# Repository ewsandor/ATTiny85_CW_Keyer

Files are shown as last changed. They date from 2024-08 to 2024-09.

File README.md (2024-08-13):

# ATTiny85_CW_Keyer
A full-featured CW keyer for amateur radio use. The keyer is built around a cheap and tiny ATTINY85 microcontroller. The circuit boasts 4-100 character memories, beacon mode, multiple timing options, and a CW trainer for improving your Morse code speed.

## Printed Circuit Board
This fork provides design files to build a PCB for this project.

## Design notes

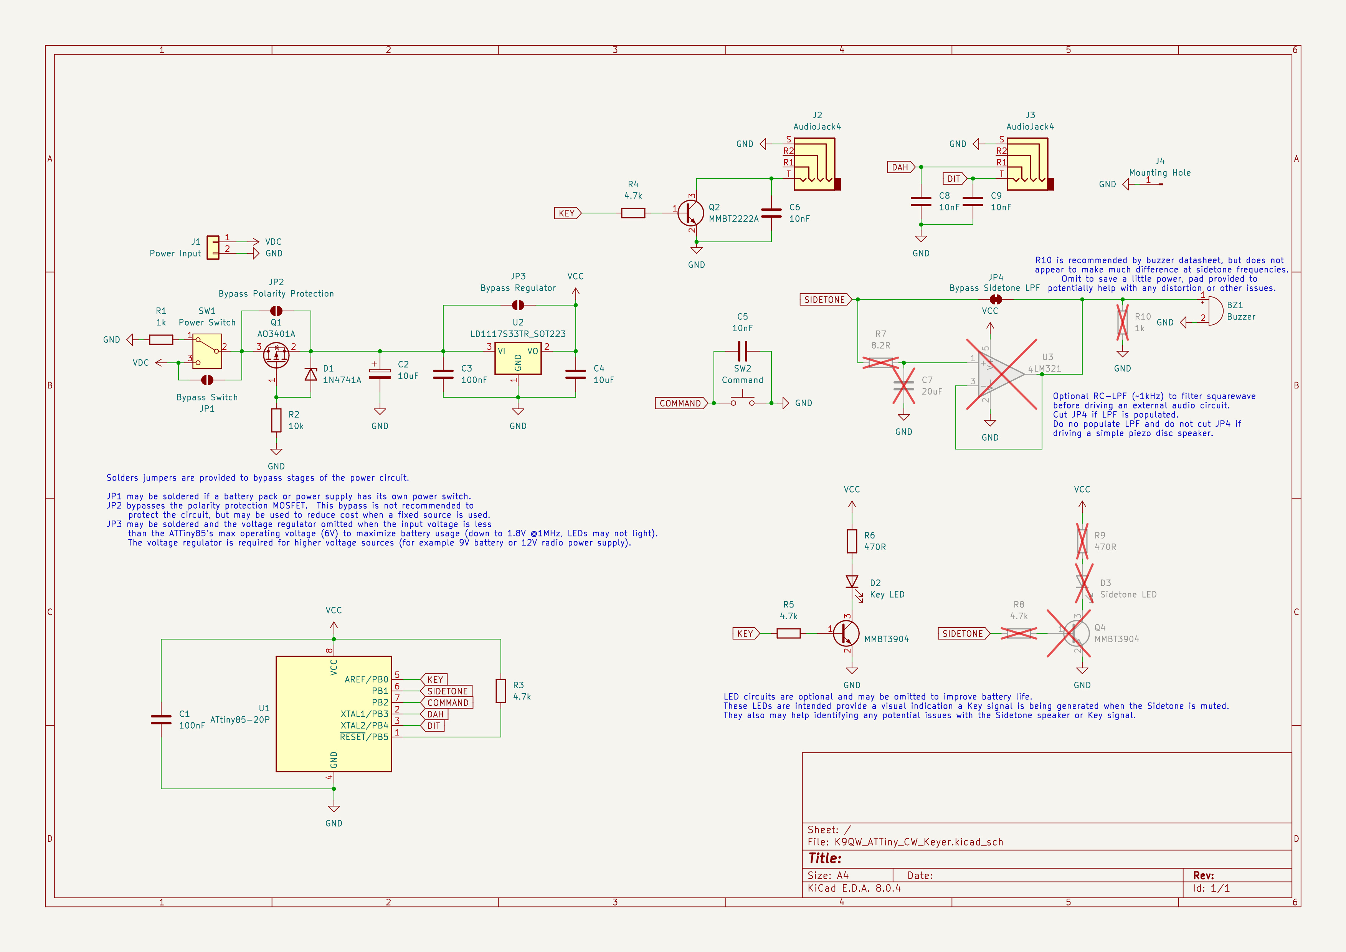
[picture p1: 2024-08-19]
schematic.jpg

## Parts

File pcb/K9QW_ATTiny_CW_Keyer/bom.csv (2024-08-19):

Reference | Value | Footprint | Qty | DNP
BZ1 | Buzzer | Buzzer_Beeper:Buzzer_TDK_PS1240P02BT_D12.2mm_H6.5mm | 1
C1,C3 | 100nF | Capacitor_SMD:C_0603_1608Metric_Pad1.08x0.95mm_HandSolder | 2
C2 | 10uF | Capacitor_THT:CP_Radial_D5.0mm_P2.00mm | 1
C4 | 10uF | Capacitor_SMD:C_0603_1608Metric_Pad1.08x0.95mm_HandSolder | 1
C5,C6,C8,C9 | 10nF | Capacitor_SMD:C_0603_1608Metric_Pad1.08x0.95mm_HandSolder | 4
C7 | 20uF | Capacitor_SMD:C_0603_1608Metric_Pad1.08x0.95mm_HandSolder | 1 | DNP
D1 | 1N4741A | Diode_THT:D_DO-41_SOD81_P3.81mm_Vertical_KathodeUp | 1
D2 | Key LED | LED_SMD:LED_0603_1608Metric_Pad1.05x0.95mm_HandSolder | 1
D3 | Sidetone LED | LED_SMD:LED_0603_1608Metric_Pad1.05x0.95mm_HandSolder | 1 | DNP
J1 | Power Input | Connector_JST:JST_XH_B2B-XH-A_1x02_P2.50mm_Vertical | 1
J2,J3 | AudioJack4 | Connector_Audio:Jack_3.5mm_PJ320D_Horizontal | 2
J4 | Mounting Hole | MountingHole:MountingHole_3.2mm_M3_Pad_TopBottom | 1
Q1 | AO3401A | Package_TO_SOT_SMD:SOT-23 | 1
Q2 | MMBT2222A | Package_TO_SOT_SMD:SOT-23 | 1
Q3 | MMBT3904 | Package_TO_SOT_SMD:SOT-23 | 1
Q4 | MMBT3904 | Package_TO_SOT_SMD:SOT-23 | 1 | DNP
R1 | 1k | Resistor_SMD:R_0603_1608Metric_Pad0.98x0.95mm_HandSolder | 1
R2 | 10k | Resistor_SMD:R_0603_1608Metric_Pad0.98x0.95mm_HandSolder | 1
R3,R4,R5 | 4.7k | Resistor_SMD:R_0603_1608Metric_Pad0.98x0.95mm_HandSolder | 3
R6 | 470R | Resistor_SMD:R_0603_1608Metric_Pad0.98x0.95mm_HandSolder | 1
R7 | 8.2R | Resistor_SMD:R_0603_1608Metric_Pad0.98x0.95mm_HandSolder | 1 | DNP
R8 | 4.7k | Resistor_SMD:R_0603_1608Metric_Pad0.98x0.95mm_HandSolder | 1 | DNP
R9 | 470R | Resistor_SMD:R_0603_1608Metric_Pad0.98x0.95mm_HandSolder | 1 | DNP
R10 | 1k | Resistor_SMD:R_0603_1608Metric_Pad0.98x0.95mm_HandSolder | 1 | DNP
SW1 | Power Switch | Connector_JST:JST_XH_B3B-XH-A_1x03_P2.50mm_Vertical | 1
SW2 | Command | Button_Switch_THT:SW_PUSH_6mm | 1
U1 | ATtiny85-20P | Package_DIP:DIP-8_W7.62mm | 1
U2 | LD1117S33TR_SOT223 | Package_TO_SOT_SMD:SOT-223-3_TabPin2 | 1
U3 | LM321 | Package_TO_SOT_SMD:SOT-23-5 | 1 | DNP

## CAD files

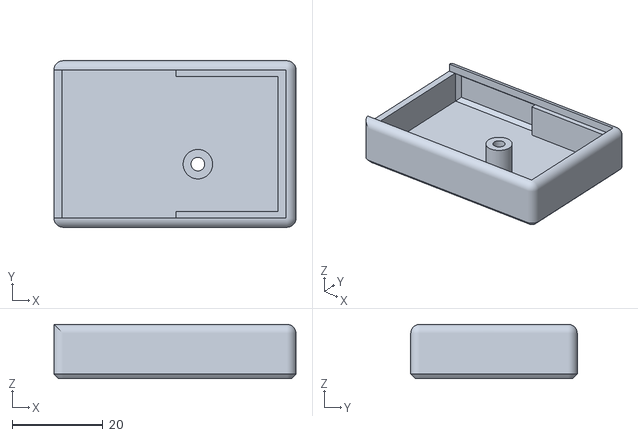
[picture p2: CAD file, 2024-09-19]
pcb/ATTiny85 CW Keyer Enclosure.stl
53.4 x 36.8 x 12.0

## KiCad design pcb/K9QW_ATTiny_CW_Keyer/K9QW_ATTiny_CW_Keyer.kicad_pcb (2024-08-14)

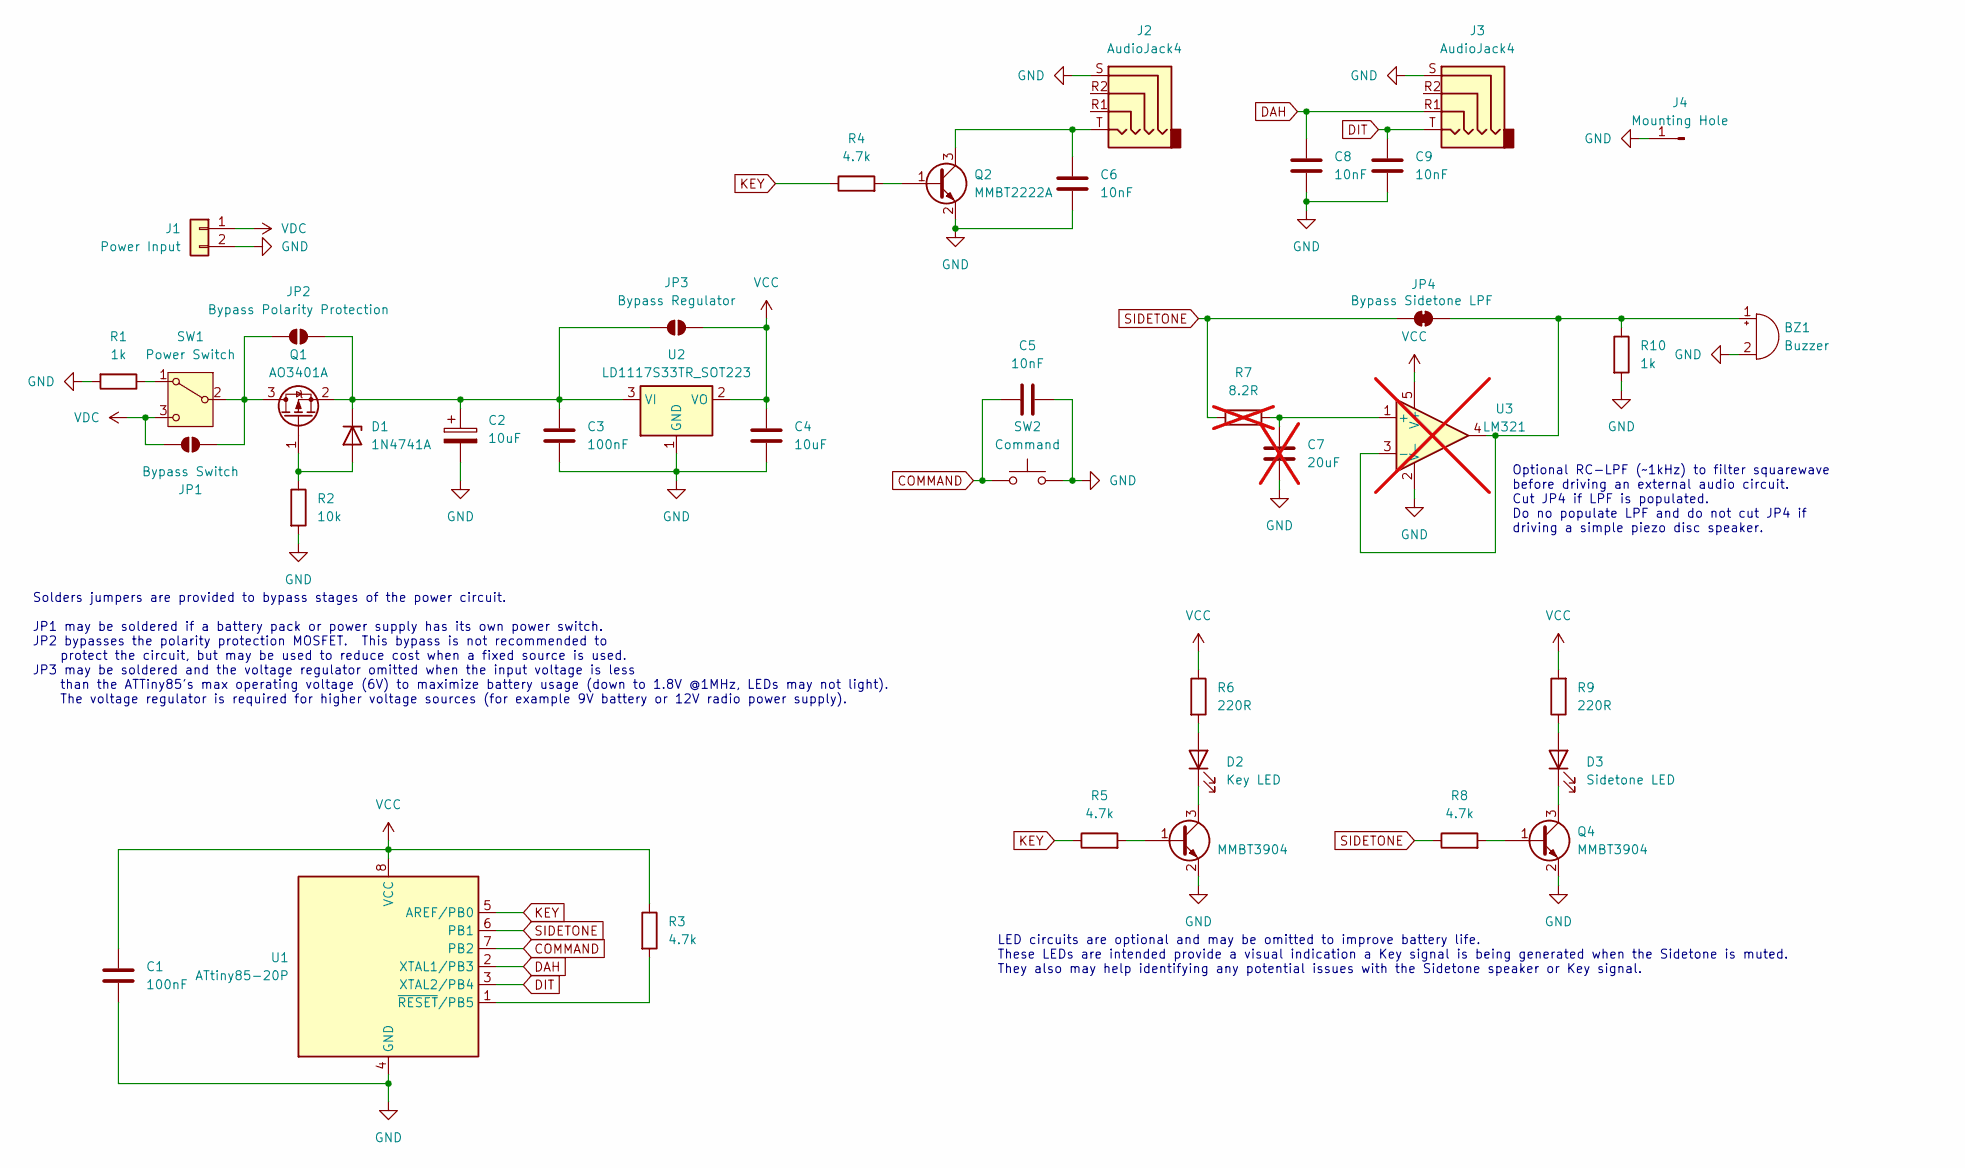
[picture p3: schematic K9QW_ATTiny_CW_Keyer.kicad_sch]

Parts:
BZ1: Buzzer; Buzzer_TDK_PS1240P02BT_D12.2mm_H6.5mm
C1, C3: 100nF; C_0603_1608Metric_Pad1.08x0.95mm_HandSolder
C2: 10uF; CP_Radial_D5.0mm_P2.00mm
C4: 10uF; C_0603_1608Metric_Pad1.08x0.95mm_HandSolder
C5, C6, C8, C9: 10nF; C_0603_1608Metric_Pad1.08x0.95mm_HandSolder
C7: 20uF; C_0603_1608Metric_Pad1.08x0.95mm_HandSolder; not fitted
D1: 1N4741A; D_DO-41_SOD81_P3.81mm_Vertical_KathodeUp
D2: Key LED; LED_0603_1608Metric_Pad1.05x0.95mm_HandSolder
D3: Sidetone LED; LED_0603_1608Metric_Pad1.05x0.95mm_HandSolder
J1: Power Input; JST_XH_B2B-XH-A_1x02_P2.50mm_Vertical
J2, J3: AudioJack4; Jack_3.5mm_PJ320D_Horizontal
J4: Mounting Hole; MountingHole_3.2mm_M3_Pad_TopBottom
JP1: Bypass Switch; SolderJumper-2_P1.3mm_Open_RoundedPad1.0x1.5mm
JP2: Bypass Polarity Protection; SolderJumper-2_P1.3mm_Open_RoundedPad1.0x1.5mm
JP3: Bypass Regulator; SolderJumper-2_P1.3mm_Open_RoundedPad1.0x1.5mm
JP4: Bypass Sidetone LPF; SolderJumper-2_P1.3mm_Bridged_RoundedPad1.0x1.5mm
Q1: AO3401A; SOT-23
Q2: MMBT2222A; SOT-23
Q3, Q4: MMBT3904; SOT-23
R1, R10: 1k; R_0603_1608Metric_Pad0.98x0.95mm_HandSolder
R2: 10k; R_0603_1608Metric_Pad0.98x0.95mm_HandSolder
R3, R4, R5, R8: 4.7k; R_0603_1608Metric_Pad0.98x0.95mm_HandSolder
R6, R9: 220R; R_0603_1608Metric_Pad0.98x0.95mm_HandSolder
R7: 8.2R; R_0603_1608Metric_Pad0.98x0.95mm_HandSolder; not fitted
SW1: Power Switch; JST_XH_B3B-XH-A_1x03_P2.50mm_Vertical
SW2: Command; SW_PUSH_6mm
U1: ATtiny85-20P; DIP-8_W7.62mm
U2: LD1117S33TR_SOT223; SOT-223-3_TabPin2
U3: LM321; SOT-23-5; not fitted

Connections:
COMMAND: C5.1, SW2.1, U1.7 (PB2)
DAH: C8.1, J3.R1, U1.2 (XTAL1/PB3)
DIT: C9.1, J3.T, U1.3 (XTAL2/PB4)
GND: BZ1.2 (-), C1.2, C2.2, C3.2, C4.2, C5.2, C6.2, C7.2, C8.2, C9.2, J1.2, J2.S, J3.S, J4.1, Q2.2 (E), Q3.2 (E), Q4.2 (E), R1.2, R2.2, R10.2, SW2.2, U1.4 (GND), U2.1 (GND), U3.2 (V-)
KEY: R4.1, R5.1, U1.5 (AREF/PB0)
unnamed: BZ1.1 (+), JP4.2 (B), R10.1, U3.3 (-), U3.4
unnamed: D1.2 (A), Q1.1 (G), R2.1
unnamed: C2.1, C3.1, D1.1 (K), JP2.2 (B), JP3.1 (A), Q1.2 (S), U2.3 (VI)
unnamed: D2.2 (A), R6.2
unnamed: D2.1 (K), Q3.3 (C)
unnamed: D3.2 (A), R9.1
unnamed: D3.1 (K), Q4.3 (C)
unnamed: JP1.1 (A), JP2.1 (A), Q1.3 (D), SW1.2 (B)
unnamed: Q2.1 (B), R4.2
unnamed: C6.1, J2.T, Q2.3 (C)
unnamed: Q3.1 (B), R5.2
unnamed: Q4.1 (B), R8.2
unnamed: R1.1, SW1.1 (A)
unnamed: R3.2, U1.1 (~RESET/PB5)
unnamed: C7.1, R7.1, U3.1 (+)
SIDETONE: JP4.1 (A), R7.2, R8.1, U1.6 (PB1)
VCC: C1.1, C4.1, JP3.2 (B), R3.1, R6.1, R9.2, U1.8 (VCC), U2.2 (VO), U3.5 (V+)
VDC: J1.1, JP1.2 (B), SW1.3 (C)

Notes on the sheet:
Optional RC-LPF (~1kHz) to filter squarewave before driving an external audio circuit. Cut JP4 if LPF is populated. Do no populate LPF and do not cut JP4 if driving a simple piezo disc speaker.
LED circuits are optional and may be omitted to improve battery life. These LEDs are intended provide a visual indication a Key signal is being generated when the Sidetone is muted. They also may help identifying any potential issues with the Sidetone speaker or Key signal.
Solders jumpers are provided to bypass stages of the power circuit. JP1 may be soldered if a battery pack or power supply has its own power switch. JP2 bypasses the polarity protection MOSFET. This bypass is not recommended to protect the circuit, but may be used to reduce cost when a fixed source 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

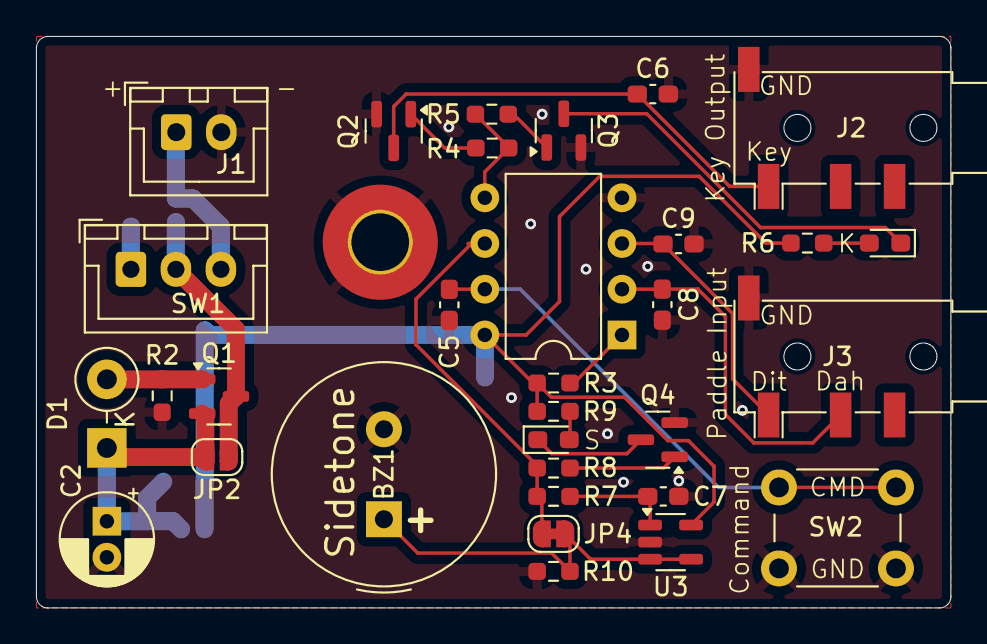
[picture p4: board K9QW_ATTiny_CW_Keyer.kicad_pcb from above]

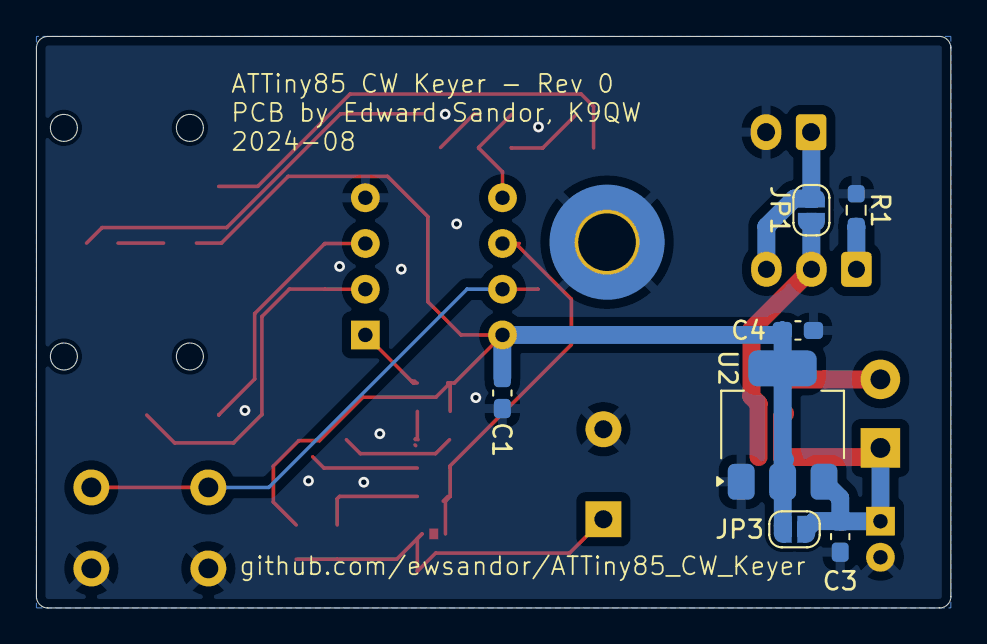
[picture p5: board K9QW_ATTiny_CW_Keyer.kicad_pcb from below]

Board: 2 copper layers, 50.8 x 31.8 mm, 40 parts (7 on the bottom side), 23 nets.

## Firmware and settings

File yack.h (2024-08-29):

/* ********************************************************************
 Program	: yack.h
 Author		: Jan Lategahn DK3LJ modified by Jack Welch AI4SV, Don Froula WD9DMP
 Purpose	: definition of keyer hardware
 Created	: 15.10.2010
 Update		: 23.12.2016
 Version	: 0.86
 
 Changelog
 ---------
 Version		Date		Change
 ----------------------------------------------------------------------
0.86          23.12.2016    Changed sidetone back to 800 Hz and mode default to iambicB  
 
 Todo
 ----
 
 
 *********************************************************************/

// User configurable settings

// The following settings define the hardware connections to the keyer chip

// Definition of where the keyer itself is connected 
#define		KEYDDR			DDRB
#define		KEYPORT			PORTB
#define		KEYINP			PINB
#define		DITPIN			4
#define		DAHPIN			3

// Definition of where the transceiver keyer line is connected
#define		OUTDDR			DDRB
#define		OUTPORT			PORTB
#define		OUTPIN			0

// Definition of where the sidetone output is connected (beware,
// this is chip dependent and can not just be changed at will)
#define		STDDR			DDRB
#define		STPORT			PORTB
#define		STPIN			1

// Definition of where the control button is connected
#define		BTNDDR			DDRB
#define		BTNPORT			PORTB
#define		BTNINP			PINB
#define		BTNPIN			2


// The following defines the meaning of status bits in the yackflags and volflags 
// global variables

// Definition of the yackflags variable. These settings get stored in EEPROM when changed.
#define		NOTUSED1		0b00000001  // Available
#define     CONFLOCK		0b00000010  // Configuration locked down
#define		MODE			0b00001100  // 2 bits to define keyer mode (see next section)
#define		SIDETONE		0b00010000  // Set if the chip must produce a sidetone
#define		TXKEY			0b00100000  // Set if the chip keys the transmitter
#define		TXINV			0b01000000  // Set if TX key line is active low
#define		PDLSWAP			0b10000000  // Set if DIT and DAH are swapped

#define		IAMBICA			0b00000000  // IAMBIC A mode
#define		IAMBICB			0b00000100  // IAMBIC B mode (default)
#define		ULTIMATIC		0b00001000  // Ultimatic Mode
#define		DAHPRIO			0b00001100  // Always give DAH priority

#define		FLAGDEFAULT		IAMBICB | TXKEY | SIDETONE

// Definition of volflags variable. These flags do not get stored in EEPROM.
#define		DITLATCH		0b00000001  // Set if DIT contact was closed
#define     DAHLATCH		0b00000010  // Set if DAH contact was closed
#define     SQUEEZED        0b00000011  // DIT and DAH = squeezed
#define		DIRTYFLAG		0b00000100  // Set if cfg data was changed and needs storing
#define     CKLATCH         0b00001000  // Set if the command key was pressed at some point
#define		VSCOPY          0b00110000  // Copies of Sidetone and TX flags from yackflags


// The following defines timing constants. In the default version the keyer is set to operate in
// 10ms heartbeat intervals. If a higher resolution is required, this can be changed to a faster
// beat

// YACK heartbeat frequency (in ms)
#define		YACKBEAT		5
#define		YACKSECS(n)		(n*(1000/YACKBEAT)) // Beats in n seconds (off by 2x for 5ms heartbeat)
#define		YACKMS(n)		(n/YACKBEAT) // Beats in n milliseconds

// Power save mode
#define     POWERSAVE       // Comment this line if no power save mode required
#define     PSTIME          20 // 20 seconds until automatic powerdown
#define     PWRWAKE         ((1<<PCINT3) | (1<<PCINT4) | (1<<PCINT2)) // Dit, Dah or Command wakes us up..

// These values limit the speed that the keyer can be set to
#define		MAXWPM			50  
#define		MINWPM			5
#define		DEFWPM			15

// Farnsworth parameters
#define     FARNSWORTH      1
#define     WPMSPEED        0
#define     MAXFARN         255

#define		WPMCALC(n)		((1200/YACKBEAT)/n) // Calculates number of beats in a dot 

#define		DITLEN			1	// Length of a dot
#define		DAHLEN			3	// Length of a dash
#define		IEGLEN			1	// Length of inter-element gap
#define		ICGLEN			3	// Length of inter-character gap
#define		IWGLEN			7	// Length of inter-word gap

// Duration of various internal timings in seconds
#define		TUNEDURATION	20  // Duration of tuning keydown (in seconds)
#define     DEFTIMEOUT      5   // Default timeout 5 seconds
#define     MACTIMEOUT      15  // Timeout after playing back a macro

// The following defines various parameters in relation to the pitch of the sidetone

// CTC mode prescaler.. If changing this, ensure that ctc config
// is adapted accordingly
#define		PRESCALE		8
#define		CTCVAL(n)		((F_CPU/n/2/PRESCALE)-1) // Defines how to compute CTC setting for
                                                     // a given frequency

// Default sidetone frequency
#define		DEFFREQ			800     // Default sidetone frequency
#define		MAXFREQ			1500    // Maximum frequency
#define		MINFREQ			400     // Minimum frequency

#define		MAXCTC			CTCVAL(MAXFREQ) // CTC values for the above three values
#define		MINCTC			CTCVAL(MINFREQ) 
#define		DEFCTC			CTCVAL(DEFFREQ)

// The following are various definitions in use throughout the program
#define		RBSIZE			100     // Size of each of the four EEPROM buffers

#define		MAGPAT			0xA5    // If this number is found in EEPROM, content assumed valid

#define		DIT				1
#define		DAH             2

#define		UP				1
#define		DOWN			2

#define		ON				1
#define		OFF				0

#define		RECORD			1
#define		PLAY			2

#define		READ			1
#define		WRITE			2

#define		TRUE            1
#define		FALSE           0


// Generic functionality
#define 	SETBIT(ADDRESS,BIT)     (ADDRESS |= (1<<BIT))
#define 	CLEARBIT(ADDRESS,BIT)   (ADDRESS &= ~(1<<BIT))

typedef		uint8_t         byte;
typedef		uint16_t        word;


// Forward declarations of public functions
void        yackinit (void);
void        yackchar(char c);
void        yackstring(const char *p);
char        yackiambic(byte ctrl);
void        yackpitch (uint8_t dir);
void        yacktune (void);
void        yackmode (uint8_t mode);
void        yackinhibit (uint8_t mode);
void        yackerror (void);
void        yacktoggle(byte flag);
byte        yackflag(byte flag);
void        yackbeat(void);
void        yackmessage(byte function, byte msgnr);
void        yacksave (void);
byte        yackctrlkey(byte mode);
void        yackreset (void);
word        yackuser (byte func, byte nr, word content);
void        yacknumber(word n);
word        yackwpm(void);
void        yackplay(byte i);
void        yackdelay(byte n);
void        yackfarns(void);
void        yackspeed (byte dir, byte mode);

#ifdef POWERSAVE
void        yackpower(byte n);
#endif

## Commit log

2024-08-11 PCB Draft
    [K9QW_ATTiny_CW_Keyer.kicad_pcb, K9QW_ATTiny_CW_Keyer.kicad_sch]
2024-08-12 Fixing LED and adding Sidetone Connector
    [K9QW_ATTiny_CW_Keyer.kicad_pcb, K9QW_ATTiny_CW_Keyer.kicad_sch]
2024-08-12 Rough PCB Layout
    [K9QW_ATTiny_CW_Keyer.kicad_pcb, K9QW_ATTiny_CW_Keyer.kicad_sch]
2024-08-12 Rough routing
    [K9QW_ATTiny_CW_Keyer.kicad_pcb]
2024-08-12 Layout cleanup
    [K9QW_ATTiny_CW_Keyer.kicad_pcb, K9QW_ATTiny_CW_Keyer.kicad_sch]
2024-08-12 Refining layout
    [K9QW_ATTiny_CW_Keyer.kicad_pcb, K9QW_ATTiny_CW_Keyer.kicad_sch]
2024-08-12 Refining routing
    [K9QW_ATTiny_CW_Keyer.kicad_pcb, K9QW_ATTiny_CW_Keyer.kicad_sch]
2024-08-12 Adding git ignore for local KiCAD Files
2024-08-12 Stripping panel mount headers
    [K9QW_ATTiny_CW_Keyer.kicad_pcb, K9QW_ATTiny_CW_Keyer.kicad_sch]
2024-08-13 Removed panel headers, added reverse polarity protection, rough layout
    [K9QW_ATTiny_CW_Keyer.kicad_pcb, K9QW_ATTiny_CW_Keyer.kicad_sch]
2024-08-13 Routing signals
    [K9QW_ATTiny_CW_Keyer.kicad_pcb]
2024-08-13 Minor adjustments
    [K9QW_ATTiny_CW_Keyer.kicad_pcb]
2024-08-13 Filter cap for command button
    [K9QW_ATTiny_CW_Keyer.kicad_pcb, K9QW_ATTiny_CW_Keyer.kicad_sch]
2024-08-13 Optional LPF and reordering input/output connectors
    [K9QW_ATTiny_CW_Keyer.kicad_pcb, K9QW_ATTiny_CW_Keyer.kicad_sch]
2024-08-13 Readme note, updated schematic, generated Gerbers
    [K9QW_ATTiny_CW_Keyer-B_Cu.gbr, K9QW_ATTiny_CW_Keyer-B_Mask.gbr, K9QW_ATTiny_CW_Keyer-B_Paste.gbr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]
2024-08-13 Rounding edges
    [K9QW_ATTiny_CW_Keyer-B_Cu.gbr, K9QW_ATTiny_CW_Keyer-B_Mask.gbr, K9QW_ATTiny_CW_Keyer-B_Paste.gbr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]
2024-08-13 Adding power supply filter cap and preparing buzzer
    [K9QW_ATTiny_CW_Keyer.kicad_pcb, K9QW_ATTiny_CW_Keyer.kicad_sch, bom.csv]
2024-08-14 Laying out buzzer and moving power regulator to back of board
    [K9QW_ATTiny_CW_Keyer.kicad_pcb]
2024-08-14 Regenerating supporting files
    [K9QW_ATTiny_CW_Keyer-B_Cu.gbr, K9QW_ATTiny_CW_Keyer-B_Mask.gbr, K9QW_ATTiny_CW_Keyer-B_Paste.gbr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]
2024-08-14 Minor adjustment
    [K9QW_ATTiny_CW_Keyer.kicad_pcb]
2024-08-14 Buffer for LPF
    [K9QW_ATTiny_CW_Keyer.kicad_pcb, K9QW_ATTiny_CW_Keyer.kicad_sch]
2024-08-14 Update release files
    [K9QW_ATTiny_CW_Keyer-B_Cu.gbr, K9QW_ATTiny_CW_Keyer-B_Mask.gbr, K9QW_ATTiny_CW_Keyer-B_Paste.gbr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]
2024-08-14 Adding resistor for 'charging and discharging to a piezoelectric element' as per buzzer datasheet.
    [K9QW_ATTiny_CW_Keyer.kicad_pcb, K9QW_ATTiny_CW_Keyer.kicad_sch]
2024-08-14 Regenerating release files
    [K9QW_ATTiny_CW_Keyer-B_Cu.gbr, K9QW_ATTiny_CW_Keyer-B_Mask.gbr, K9QW_ATTiny_CW_Keyer-B_Paste.gbr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]
2024-08-18 Even shorter power save interval
    [yack.h]
2024-08-19 Default sidetone of 600Hz
2024-08-19 Recommend omitting sidetone LED by default
    [K9QW_ATTiny_CW_Keyer.kicad_sch]
2024-08-19 Update exported schematic and bom
    [bom.csv]
2024-08-29 Matching dit/dah pins to PCB, set 800hz sidetone to match Kenwood TS-690s
2024-09-19 Simple enclosure to contain PCB and 2032 Battery
    [ATTiny85 CW Keyer Enclosure.stl]
